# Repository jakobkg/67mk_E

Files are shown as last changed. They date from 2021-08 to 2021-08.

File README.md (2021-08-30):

# 67mk_E

[][cc-by-nc-sa]<a href="https://ko-fi.com/kb_elmo">kofibadge</a>

### A simple "no frills" drop-in replacement PCB for the KBDfans 67mkII / 67lite

header

---

[KiCAD PCB files](pcb/)

[Gerbers for PCB production](pcb/gerbers/)

[JLCPCB BOM](pcb/fab/67_E_bom_jlc.csv)

[JLCPCB CPL](pcb/fab/67_E_cpl_jlc.csv)

[Vial-QMK firmware](firmware/)

---

pcb_back
pcb_front

---

This work is licensed under a
[Creative Commons Attribution-NonCommercial-ShareAlike 4.0 International License][cc-by-nc-sa].

[][cc-by-nc-sa]

[cc-by-nc-sa]: http://creativecommons.org/licenses/by-nc-sa/4.0/
[cc-by-nc-sa-image]: https://licensebuttons.net/l/by-nc-sa/4.0/88x31.png
[cc-by-nc-sa-shield]: https://img.shields.io/badge/License-CC%20BY--NC--SA%204.0-lightgrey.svg

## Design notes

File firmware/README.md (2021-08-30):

# 67mk_E - Vial-QMK

67mk_e

A simple "no frills" drop-in replacement PCB for the KBDfans 67mkII / 67lite

* Keyboard Maintainer: [kb-elmo](https://github.com/kb-elmo)
* Hardware Supported: 67mk_E rev.1 PCB
* Hardware Availability: [Open source project](https://github.com/kb-elmo/67mk_e)

Make example for this keyboard (after setting up your build environment):

    make kb_elmo/67mk_e:default

Flashing example for this keyboard:

    make kb_elmo/67mk_e:default:flash

**Bootloader:** Press the physical reset button on the bottom side of the PCB (labeled Reset) or hold down the top left key while plugging in the board.

See the [build environment setup](https://docs.qmk.fm/#/getting_started_build_tools) and the [make instructions](https://docs.qmk.fm/#/getting_started_make_guide) for more information. Brand new to QMK? Start with our [Complete Newbs Guide](https://docs.qmk.fm/#/newbs).

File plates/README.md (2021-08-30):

# KBD67lite platefiles

These platefiles were modified from the original KBDfans ones and provided to me by tiggggr.  
The plates are available in fixed ANSI and fixed ISO version, both with support for split backspace and both 6.25u and 7u bottom rows.

The possible layouts are listed below.

#### ANSI plate
ansiplate

#### ISO plate
isoplate

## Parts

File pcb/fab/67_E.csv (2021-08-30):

Comment | Designator | Footprint | LCSC
10uF | C1 | Capacitor_SMD:C_0805_2012Metric | C91245
C | C17,C18,C19,C20 | Capacitor_SMD:C_0805_2012Metric
0.1uF | C2,C3,C4,C5 | Capacitor_SMD:C_0805_2012Metric | C49678
0.1u | C6,C10,C11,C12,C13,C14,C15,C16 | Capacitor_SMD:C_0805_2012Metric
1uF | C7 | Capacitor_SMD:C_0805_2012Metric | C28323
22pF | C8,C9 | Capacitor_SMD:C_0805_2012Metric | C1804
WS2812B | D16,D37,D38,D39,D40,D41,D42,D43,D44,D45,D46,D47 | LED_SMD:LED_WS2812B_PLCC4_5.0x5.0mm_P3.2mm
D_Small | D1,D2,D3,D4,D5,D6,D7,D8,D9,D10,D11,D12,D13,D14,D15,D17,D18,D19,D20,D21,D22,D23,D24,D25,D26,D27,D28,D29,D30,D31,D32,D33,D34,D35,D36 | custom_parts:D_SOT-23_ANK | C68978
Polyfuse_Small | F1 | Fuse:Fuse_1206_3216Metric | C69688
MX-NoLED | MX1 | MX_Only:MXOnly-2U-Hotswap
MX-NoLED | MX19 | MX_Only:MXOnly-1.5U-Hotswap
MX-NoLED | MX2,MX3,MX4,MX5,MX6,MX7,MX8,MX9,MX10,MX11,MX12,MX13,MX14,MX17,MX18,MX20,MX21,MX22,MX23,MX24,MX25,MX26,MX27,MX28,MX29,MX30,MX31,MX33,MX37,MX38,MX39,MX40,MX41,MX42,MX43,MX44,MX45,MX46,MX47,MX49,MX52,MX53,MX54,MX55,MX56,MX57,MX58,MX59,MX60,MX61,MX62,MX64,MX65,MX77,MX78,MX79 | MX_Only:MXOnly-1U-Hotswap
MX-NoLED | MX35 | MX_Only:MXOnly-ISO-Hotswap-ReversedStabilizers
MX-NoLED | MX36,MX63 | MX_Only:MXOnly-1.75U-Hotswap
MX-NoLED | MX50,MX71,MX72,MX73,MX75,MX76 | MX_Only:MXOnly-1.25U-Hotswap
MX-NoLED | MX74 | MX_Only:MXOnly-6.25U-Hotswap-ReversedStabilizers
5.1k | R1,R2 | Resistor_SMD:R_0805_2012Metric | C27834
22 | R3,R4 | Resistor_SMD:R_0805_2012Metric | C17561
10k | R5,R6 | Resistor_SMD:R_0805_2012Metric | C17414
SW_Push | RESET1 | Button_Switch_SMD:SW_SPST_TL3342 | C318884
ATmega32U4-AU | U1 | Package_QFP:TQFP-44_10x10mm_P0.8mm | C44854
SRV05-4 | U2 | Package_TO_SOT_SMD:SOT-23-6 | C85364
USB_C_Receptacle_USB2.0 | USB1 | Connector_USB:USB_C_Receptacle_HRO_TYPE-C-31-M-12 | C165948
Crystal_GND24_Small | X1 | Crystal:Crystal_SMD_3225-4Pin_3.2x2.5mm | C13738

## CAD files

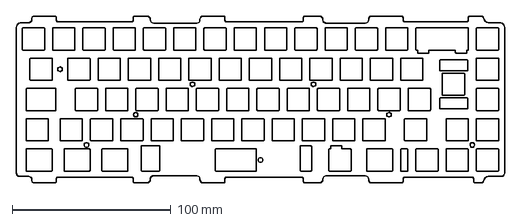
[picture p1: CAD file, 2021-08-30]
plates/ISO.dxf
307.3 x 104.9 mm

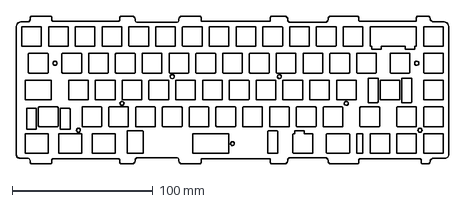
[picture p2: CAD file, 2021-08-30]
plates/ANSI.dxf
307.3 x 104.9 mm

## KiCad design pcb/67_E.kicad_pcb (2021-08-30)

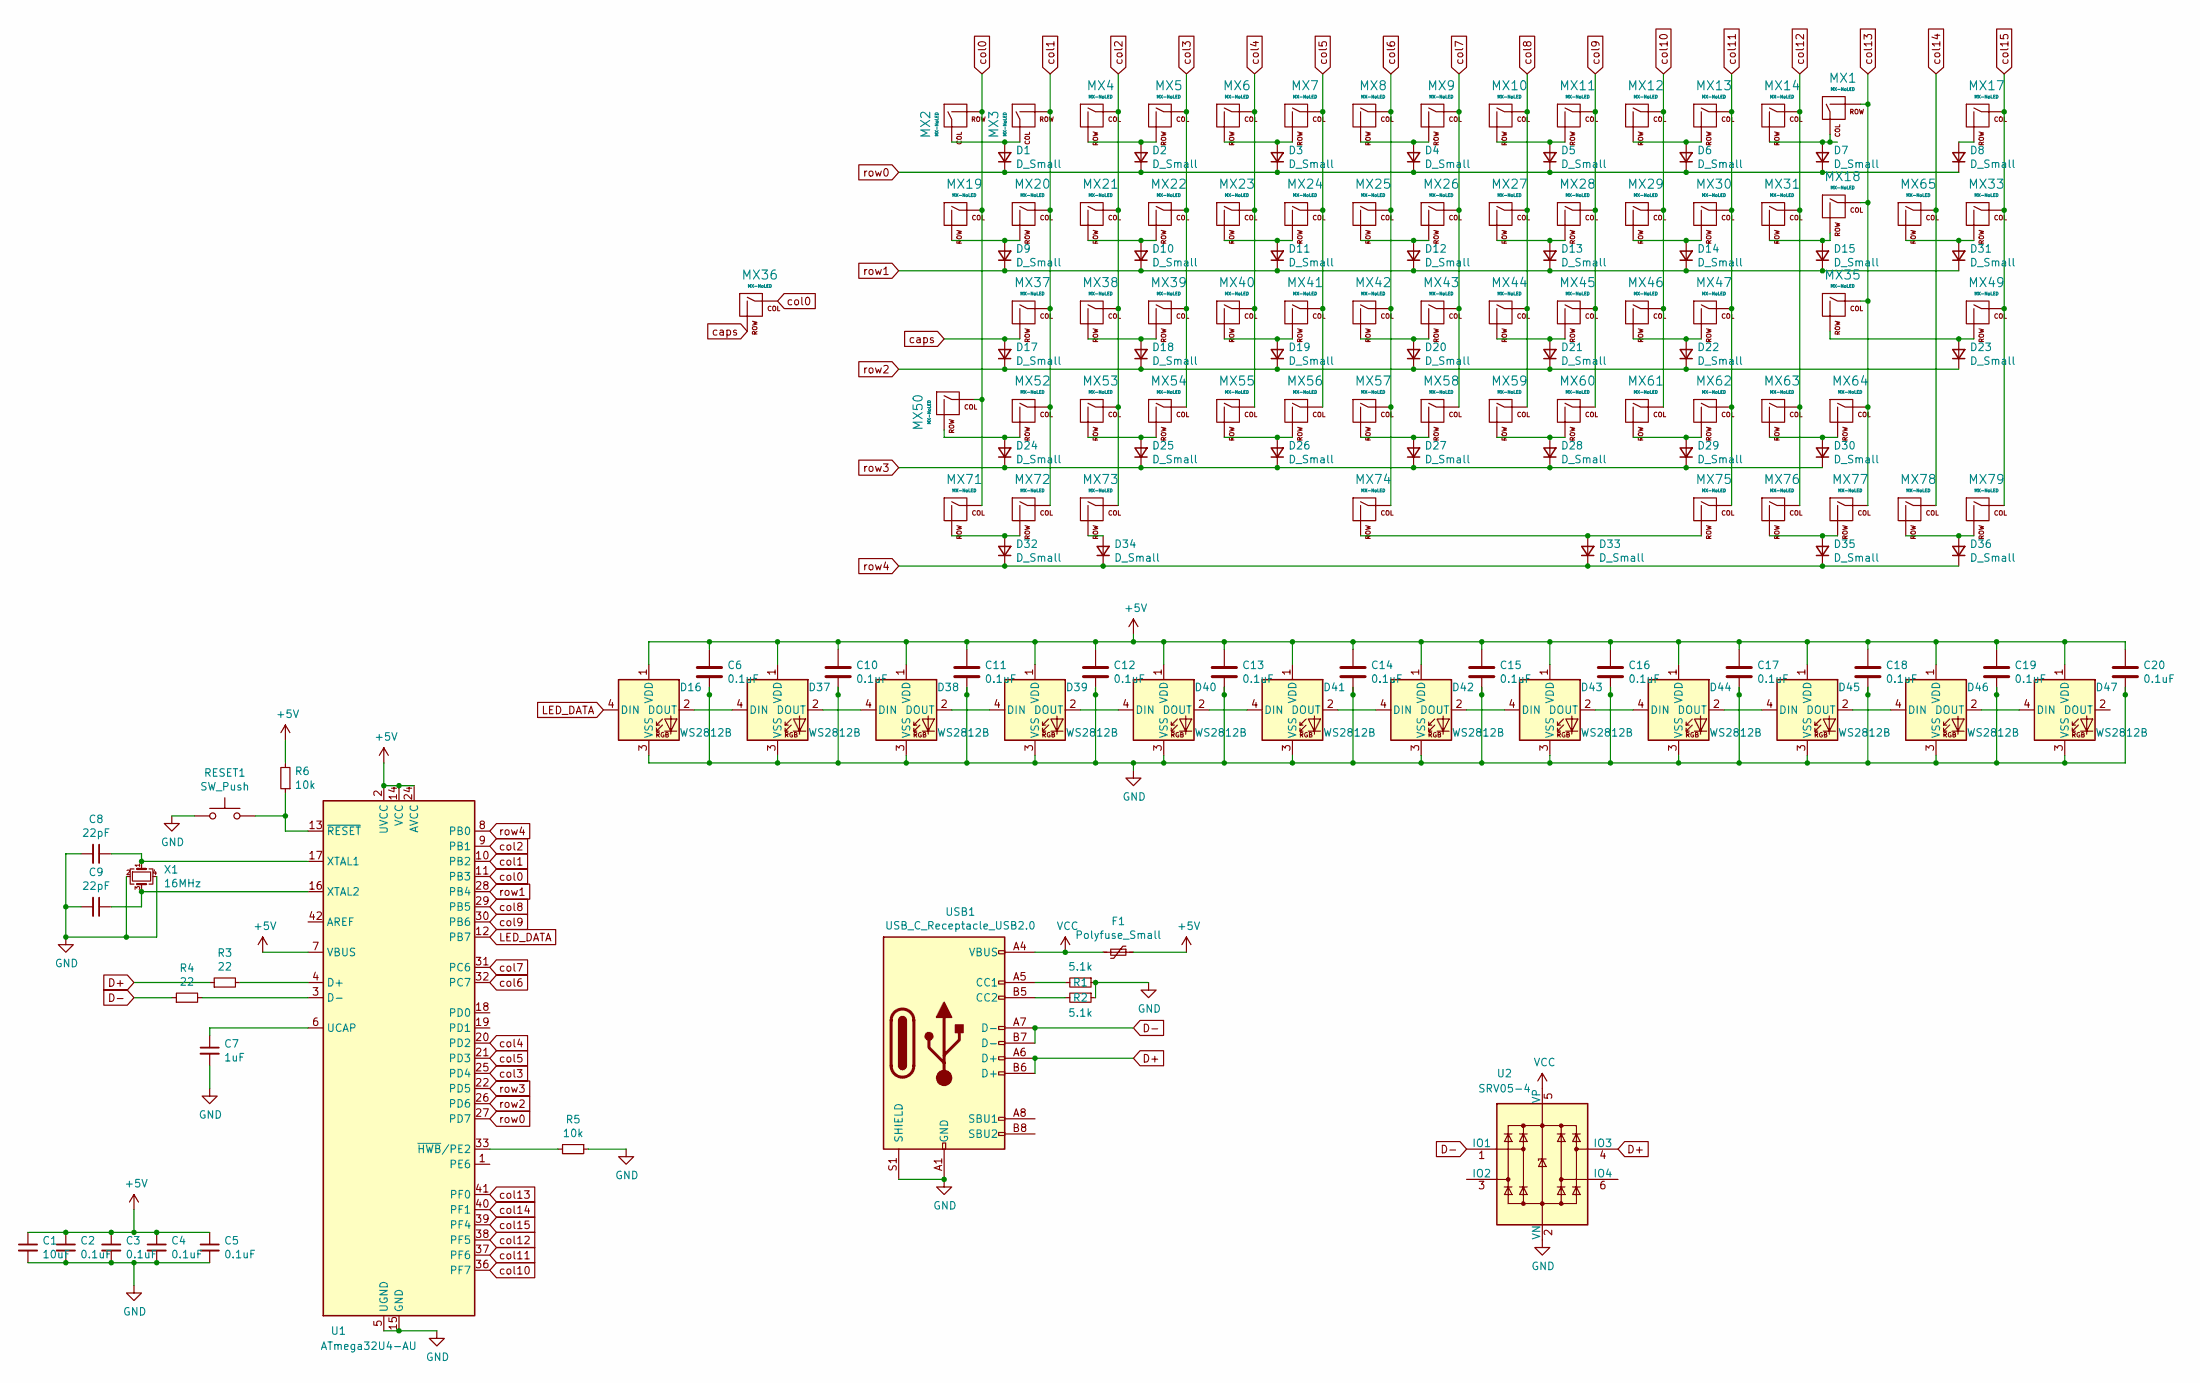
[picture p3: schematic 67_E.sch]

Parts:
C1: 10uF; C_0805_2012Metric; LCSC C91245
C2, C3, C4, C5: 0.1uF; C_0805_2012Metric; LCSC C49678
C6, C10, C11, C12, C13, C14, C15, C16, C17, C18, C19, C20: 0.1uF; C_0805_2012Metric
C7: 1uF; C_0805_2012Metric; LCSC C28323
C8, C9: 22pF; C_0805_2012Metric; LCSC C1804
D1, D2, D3, D4, D5, D6, D7, D8, D9, D10, D11, D12, D13, D14, D15, D17, D18, D19, D20, D21, D22, D23, D24, D25, D26, D27, D28, D29, D30, D31, D32, D33, D34, D35, D36: D_Small; D_SOT-23_ANK; LCSC C68978
D16, D37, D38, D39, D40, D41, D42, D43, D44, D45, D46, D47: WS2812B; LED_WS2812B_PLCC4_5.0x5.0mm_P3.2mm
F1: Polyfuse_Small; Fuse_1206_3216Metric; LCSC C69688
MX1: MX-NoLED; MXOnly-2U-Hotswap
MX2, MX3, MX4, MX5, MX6, MX7, MX8, MX9, MX10, MX11, MX12, MX13, MX14, MX17, MX18, MX20, MX21, MX22, MX23, MX24, MX25, MX26, MX27, MX28, MX29, MX30, MX31, MX33, MX37, MX38, MX39, MX40, MX41, MX42, MX43, MX44, MX45, MX46, MX47, MX49, MX52, MX53, MX54, MX55, MX56, MX57, MX58, MX59, MX60, MX61, MX62, MX64, MX65, MX77, MX78, MX79: MX-NoLED; MXOnly-1U-Hotswap
MX19: MX-NoLED; MXOnly-1.5U-Hotswap
MX35: MX-NoLED; MXOnly-ISO-Hotswap-ReversedStabilizers
MX36, MX63: MX-NoLED; MXOnly-1.75U-Hotswap
MX50, MX71, MX72, MX73, MX75, MX76: MX-NoLED; MXOnly-1.25U-Hotswap
MX74: MX-NoLED; MXOnly-6.25U-Hotswap-ReversedStabilizers
R1, R2: 5.1k; R_0805_2012Metric; LCSC C27834
R3, R4: 22; R_0805_2012Metric; LCSC C17561
R5, R6: 10k; R_0805_2012Metric; LCSC C17414
RESET1: SW_Push; TestPoint_2Pads_Pitch2.54mm_Drill0.8mm; LCSC C318884
U1: ATmega32U4-AU; TQFP-44_10x10mm_P0.8mm; LCSC C44854
U2: SRV05-4; SOT-23-6; LCSC C85364
USB1: USB_C_Receptacle_USB2.0; USB_C_Receptacle_HRO_TYPE-C-31-M-12; LCSC C165948
X1: 16MHz; Crystal_SMD_3225-4Pin_3.2x2.5mm; LCSC C13738

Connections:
+5V: C1.1, C2.1, C3.1, C4.1, C5.1, C6.1, C10.1, C11.1, C12.1, C13.1, C14.1, C15.1, C16.1, C17.1, C18.1, C19.1, C20.1, D16.1 (VDD), D37.1 (VDD), D38.1 (VDD), D39.1 (VDD), D40.1 (VDD), D41.1 (VDD), D42.1 (VDD), D43.1 (VDD), D44.1 (VDD), D45.1 (VDD), D46.1 (VDD), D47.1 (VDD), F1.1, R6.2, U1.2 (UVCC), U1.7 (VBUS), U1.14 (VCC), U1.24 (AVCC), U1.34 (VCC), U1.44 (AVCC)
D+: R3.1, U2.4 (IO3), USB1.A6 (D+), USB1.B6 (D+)
D-: R4.1, U2.1 (IO1), USB1.A7 (D-), USB1.B7 (D-)
GND: C1.2, C2.2, C3.2, C4.2, C5.2, C6.2, C7.2, C8.2, C9.2, C10.2, C11.2, C12.2, C13.2, C14.2, C15.2, C16.2, C17.2, C18.2, C19.2, C20.2, D16.3 (VSS), D37.3 (VSS), D38.3 (VSS), D39.3 (VSS), D40.3 (VSS), D41.3 (VSS), D42.3 (VSS), D43.3 (VSS), D44.3 (VSS), D45.3 (VSS), D46.3 (VSS), D47.3 (VSS), R1.1, R2.1, R5.1, RESET1.1, U1.5 (UGND), U1.15 (GND), U1.23 (GND), U1.35 (GND), U1.43 (GND), U2.2 (VN), USB1.A1 (GND), USB1.A12 (GND), USB1.B1 (GND), USB1.B12 (GND), USB1.S1 (SHIELD), X1.2, X1.4
LED_DATA: D16.4 (DIN), U1.12 (PB7)
unnamed: C7.1, U1.6 (UCAP)
unnamed: C8.1, U1.17 (XTAL1), X1.1
unnamed: C9.1, U1.16 (XTAL2), X1.3
unnamed: D1.2 (A), MX2.1 (COL), MX3.1 (COL)
unnamed: D2.2 (A), MX4.2 (ROW), MX5.2 (ROW)
unnamed: D3.2 (A), MX6.2 (ROW), MX7.2 (ROW)
unnamed: D4.2 (A), MX8.2 (ROW), MX9.2 (ROW)
unnamed: D5.2 (A), MX10.2 (ROW), MX11.2 (ROW)
unnamed: D6.2 (A), MX12.2 (ROW), MX13.2 (ROW)
unnamed: D7.2 (A), MX1.1 (COL), MX14.2 (ROW)
unnamed: D8.2 (A), MX17.2 (ROW)
unnamed: D9.2 (A), MX19.2 (ROW), MX20.2 (ROW)
unnamed: D10.2 (A), MX21.2 (ROW), MX22.2 (ROW)
unnamed: D11.2 (A), MX23.2 (ROW), MX24.2 (ROW)
unnamed: D12.2 (A), MX25.2 (ROW), MX26.2 (ROW)
unnamed: D13.2 (A), MX27.2 (ROW), MX28.2 (ROW)
unnamed: D14.2 (A), MX29.2 (ROW), MX30.2 (ROW)
unnamed: D15.2 (A), MX18.2 (ROW), MX31.2 (ROW)
unnamed: D16.2 (DOUT), D37.4 (DIN)
unnamed: D18.2 (A), MX38.2 (ROW), MX39.2 (ROW)
unnamed: D19.2 (A), MX40.2 (ROW), MX41.2 (ROW)
unnamed: D20.2 (A), MX42.2 (ROW), MX43.2 (ROW)
unnamed: D21.2 (A), MX44.2 (ROW), MX45.2 (ROW)
unnamed: D22.2 (A), MX46.2 (ROW), MX47.2 (ROW)
unnamed: D23.2 (A), MX35.2 (ROW), MX49.2 (ROW)
unnamed: D24.2 (A), MX50.2 (ROW), MX52.2 (ROW)
unnamed: D25.2 (A), MX53.2 (ROW), MX54.2 (ROW)
unnamed: D26.2 (A), MX55.2 (ROW), MX56.2 (ROW)
unnamed: D27.2 (A), MX57.2 (ROW), MX58.2 (ROW)
unnamed: D28.2 (A), MX59.2 (ROW), MX60.2 (ROW)
unnamed: D29.2 (A), MX61.2 (ROW), MX62.2 (ROW)
unnamed: D30.2 (A), MX63.2 (ROW), MX64.2 (ROW)
unnamed: D31.2 (A), MX33.2 (ROW), MX65.2 (ROW)
unnamed: D32.2 (A), MX71.2 (ROW), MX72.2 (ROW)
unnamed: D33.2 (A), MX74.2 (ROW), MX75.2 (ROW)
unnamed: D34.2 (A), MX73.2 (ROW)
unnamed: D35.2 (A), MX76.2 (ROW), MX77.2 (ROW)
unnamed: D36.2 (A), MX78.2 (ROW), MX79.2 (ROW)
unnamed: D37.2 (DOUT), D38.4 (DIN)
unnamed: D38.2 (DOUT), D39.4 (DIN)
unnamed: D39.2 (DOUT), D40.4 (DIN)
unnamed: D40.2 (DOUT), D41.4 (DIN)
unnamed: D41.2 (DOUT), D42.4 (DIN)
unnamed: D42.2 (DOUT), D43.4 (DIN)
unnamed: D43.2 (DOUT), D44.4 (DIN)
unnamed: D44.2 (DOUT), D45.4 (DIN)
unnamed: D45.2 (DOUT), D46.4 (DIN)
unnamed: D46.2 (DOUT), D47.4 (DIN)
unnamed: R1.2, USB1.A5 (CC1)
unnamed: R2.2, USB1.B5 (CC2)
unnamed: R3.2, U1.4 (D+)
unnamed: R4.2, U1.3 (D-)
unnamed: R5.2, U1.33 (~HWB~/PE2)
unnamed: R6.1, RESET1.2, U1.13 (~RESET)
VCC: F1.2, U2.5 (VP), USB1.A4 (VBUS), USB1.A9 (VBUS), USB1.B4 (VBUS), USB1.B9 (VBUS)
caps: D17.2 (A), MX36.2 (ROW), MX37.2 (ROW)
col0: MX2.2 (ROW), MX19.1 (COL), MX36.1 (COL), MX50.1 (COL), MX71.1 (COL), U1.11 (PB3)
col1: MX3.2 (ROW), MX20.1 (COL), MX37.1 (COL), MX52.1 (COL), MX72.1 (COL), U1.10 (PB2)
col2: MX4.1 (COL), MX21.1 (COL), MX38.1 (COL), MX53.1 (COL), MX73.1 (COL), U1.9 (PB1)
col3: MX5.1 (COL), MX22.1 (COL), MX39.1 (COL), MX54.1 (COL), U1.25 (PD4)
col4: MX6.1 (COL), MX23.1 (COL), MX40.1 (COL), MX55.1 (COL), U1.20 (PD2)
col5: MX7.1 (COL), MX24.1 (COL), MX41.1 (COL), MX56.1 (COL), U1.21 (PD3)
col6: MX8.1 (COL), MX25.1 (COL), MX42.1 (COL), MX57.1 (COL), MX74.1 (COL), U1.32 (PC7)
col7: MX9.1 (COL), MX26.1 (COL), MX43.1 (COL), MX58.1 (COL), U1.31 (PC6)
col8: MX10.1 (COL), MX27.1 (COL), MX44.1 (COL), MX59.1 (COL), U1.29 (PB5)
col9: MX11.1 (COL), MX28.1 (COL), MX45.1 (COL), MX60.1 (COL), U1.30 (PB6)
col10: MX12.1 (COL), MX29.1 (COL), MX46.1 (COL), MX61.1 (COL), U1.36 (PF7)
col11: MX13.1 (COL), MX30.1 (COL), MX47.1 (COL), MX62.1 (COL), MX75.1 (COL), U1.37 (PF6)
col12: MX14.1 (COL), MX31.1 (COL), MX63.1 (COL), MX76.1 (COL), U1.38 (PF5)
col13: MX1.2 (ROW), MX18.1 (COL), MX35.1 (COL), MX64.1 (COL), MX77.1 (COL), U1.41 (PF0)
col14: MX65.1 (COL), MX78.1 (COL), U1.40 (PF1)
col15: MX17.1 (COL), MX33.1 (COL), MX49.1 (COL), MX79.1 (COL), U1.39 (PF4)
row0: D1.1 (K), D2.1 (K), D3.1 (K), D4.1 (K), D5.1 (K), D6.1 (K), D7.1 (K), D8.1 (K), U1.27 (PD7)
row1: D9.1 (K), D10.1 (K), D11.1 (K), D12.1 (K), D13.1 (K), D14.1 (K), D15.1 (K), D31.1 (K), U1.28 (PB4)
row2: D17.1 (K), D18.1 (K), D19.1 (K), D20.1 (K), D21.1 (K), D22.1 (K), D23.1 (K), U1.26 (PD6)
row3: D24.1 (K), D25.1 (K), D26.1 (K), D27.1 (K), D28.1 (K), D29.1 (K), D30.1 (K), U1.22 (PD5)
row4: D32.1 (K), D33.1 (K), D34.1 (K), D35.1 (K), D36.1 (K), U1.8 (PB0)

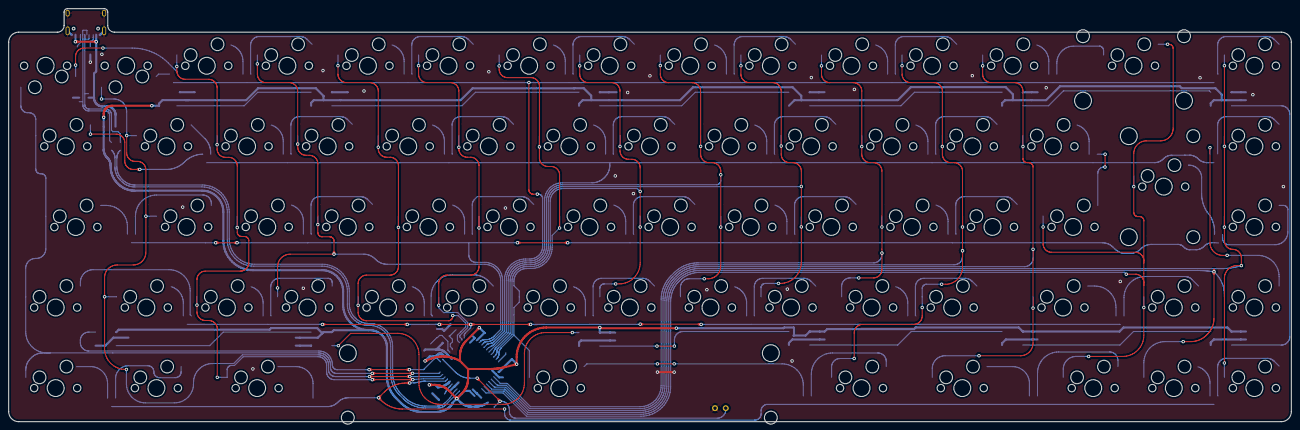
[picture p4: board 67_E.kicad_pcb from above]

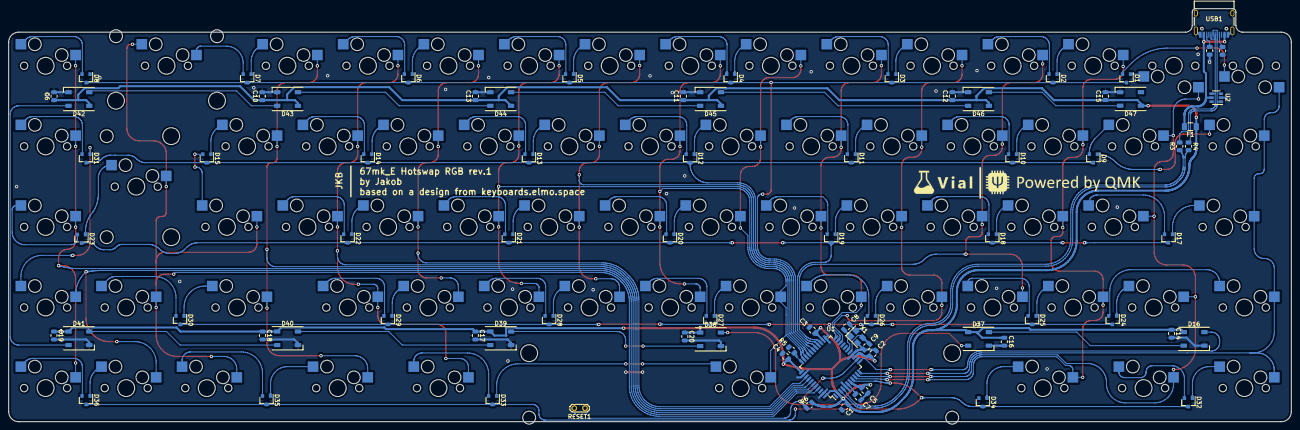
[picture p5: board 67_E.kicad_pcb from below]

Board: 2 copper layers, 303.2 x 97.6 mm, 147 parts (79 on the bottom side), 82 nets.

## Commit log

2021-08-12 replace all switch footprints with hotswap equivalents and begin re-routing PCB
    [67_E.sch]
2021-08-13 Re-trace USB port, fuse and ESD
    [67_E.kicad_pcb]
2021-08-14 finish rerouting switch matrix
    [67_E.kicad_pcb]
2021-08-14 remove unused LED footprint
    [67_E.sch]
2021-08-15 Add RGB underglow to PCB
    [67_E.kicad_pcb, 67_E.sch]
2021-08-15 remove unneeded backup/cache files
    [67_E.csv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]

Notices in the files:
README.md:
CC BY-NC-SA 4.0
